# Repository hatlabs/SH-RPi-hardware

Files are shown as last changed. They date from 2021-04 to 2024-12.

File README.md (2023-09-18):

# Sailor Hat for Raspberry Pi (SH-RPi)

## Introduction

The Sailor Hat for Raspberry Pi (SH-RPi) is a versatile power management board designed for the Raspberry Pi and similar single-board computers. With the SH-RPi connected, you can create deeply integrated servers that shut down safely when power is turned off and wake up automatically when power is restored.

SH-RPi supports all Raspberry Pi models with a 40-pin GPIO header (every model since the Pi 1 Model B+). Additionally, it is compatible with Raspberry Pi Compute Module 4 boards and other single-board computers that have a 40-pin Raspberry Pi-compatible GPIO header or an external I2C interface with a 5V power input.

The [documentation site](https://docs.hatlabs.fi/sh-rpi/) has details on the hardware and software features of the board.

This repository contains the KiCad hardware design files for Sailor Hat.
There are two other related repositories: 
[firmware](https://github.com/hatlabs/SH-RPi-firmware) and 
[daemon](https://github.com/hatlabs/SH-RPi-daemon).

The documentation site is at [docs.hatlabs.fi/sh-rpi](https://docs.hatlabs.fi/). The devices are available for purchase at [shop.hatlabs.fi](https://shop.hatlabs.fi).

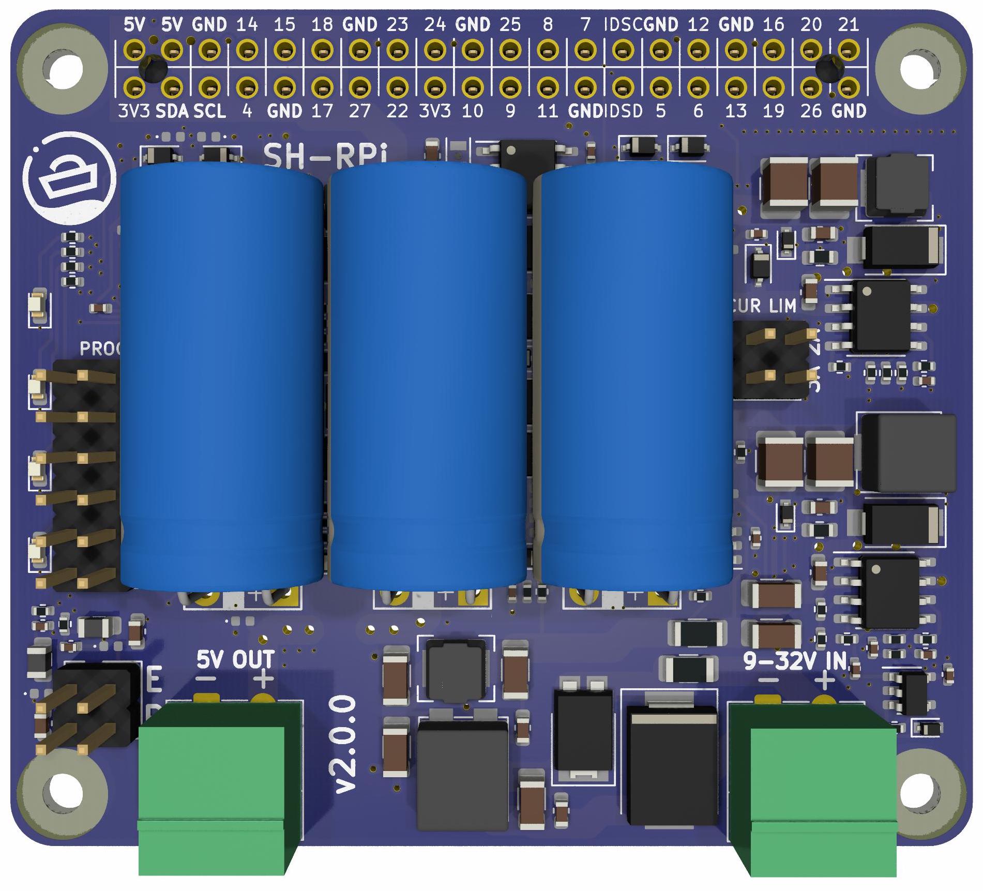
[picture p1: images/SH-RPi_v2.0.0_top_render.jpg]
SH-RPi v2.0.0


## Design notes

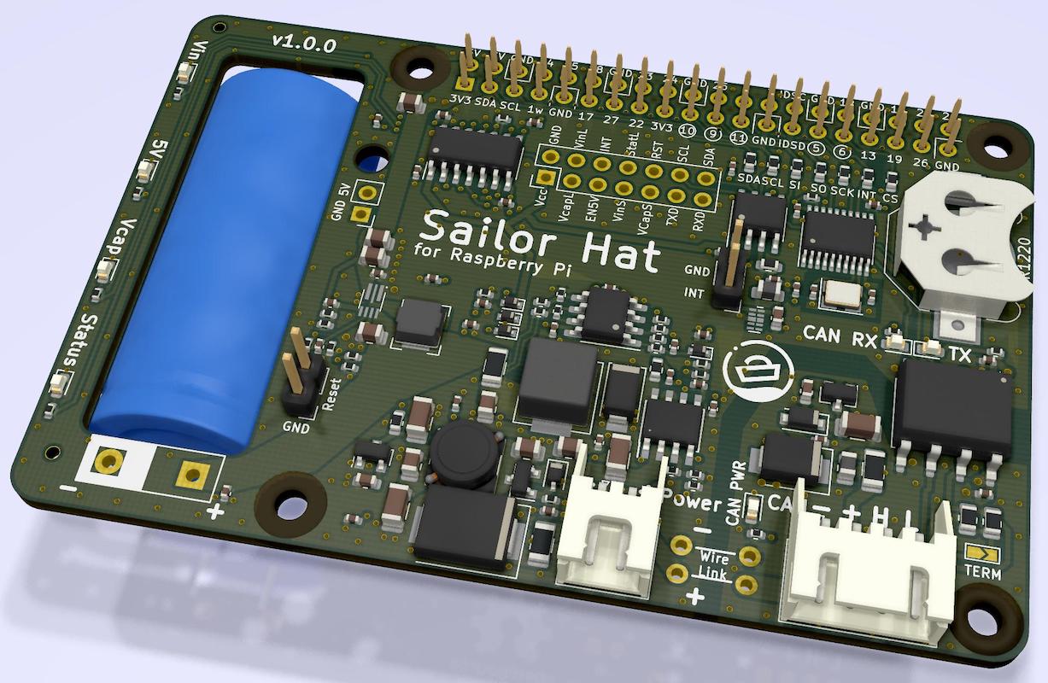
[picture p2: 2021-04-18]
images/SH-RPi-v1.0.0-render.jpg

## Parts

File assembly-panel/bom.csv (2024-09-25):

Comment | Designator | Footprint | LCSC
Conn_01x02 | J101,J502 | Connector_Phoenix_MC:PhoenixContact_MC_1,5_2-G-3.81_1x02_P3.81mm_Horizontal | C8387
100nF | C305,C306,C311,C312,C403,C406,C803,C1001,C1002,C1003 | Capacitor_SMD:C_0402_1005Metric | C1525
10k | R303,R311,R407,R409 | Resistor_SMD:R_0402_1005Metric | C25744
56k | R401 | Resistor_SMD:R_0402_1005Metric | C25796
2k | R404 | Resistor_SMD:R_0402_1005Metric | C4109
20k | R403 | Resistor_SMD:R_0402_1005Metric | C25765
150k | R402,R1005,R1008,R1011 | Resistor_SMD:R_0402_1005Metric | C25755
33pF 50V | C401,C402 | Capacitor_SMD:C_0603_1608Metric | C1663
33pF | C404,C405 | Capacitor_SMD:C_0402_1005Metric | C1562
GZ2012D601TF | FB401,FB402 | Inductor_SMD:L_0805_2012Metric | C1017
100R | R308,R405,R406 | Resistor_SMD:R_0402_1005Metric | C25076
ESD5451N | D401,D402,D501,D503,D505 | Diode_SMD:D_0402_1005Metric | C2936977
Conn_02x06_Odd_Even | J402 | Connector_PinHeader_2.54mm:PinHeader_2x06_P2.54mm_Vertical | C5383107
1k | R206,R408,R501,R502,R503,R504 | Resistor_SMD:R_0402_1005Metric | C11702
100k | R302,R410 | Resistor_SMD:R_0402_1005Metric | C25741
ATtiny1616-MNR | U401 | Package_DFN_QFN:VQFN-20-1EP_3x3mm_P0.4mm_EP1.7x1.7mm | C507118
Conn_02x02_Top_Bottom | J401 | Connector_PinHeader_2.54mm:PinHeader_2x02_P2.54mm_Vertical | C492419
100nF | C203,C308 | Capacitor_SMD:C_0603_1608Metric | C14663
SLO0530H3R3MTT | L301 | SH-RPi:L_MWSA0503S | C325963
47uF 16V | C309,C310 | Capacitor_SMD:C_1210_3225Metric | C77101
47k | R313 | Resistor_SMD:R_0402_1005Metric | C25792
470k | R312 | Resistor_SMD:R_0402_1005Metric | C25790
10m | R301 | Resistor_SMD:R_1206_3216Metric | C105362
1N4148WT | D201,D302,D305 | Diode_SMD:D_SOD-523 | C414017
5.1R | R202,R309 | Resistor_SMD:R_0603_1608Metric | C25197
68k | R204,R307 | Resistor_SMD:R_0402_1005Metric | C36871
SS56FL | D303 | Diode_SMD:D_SMA | C122865
1uF 50V | C303 | Capacitor_SMD:C_0603_1608Metric | C15849
10uF 50V | C301,C302,C702,C703,C704,C705 | Capacitor_SMD:C_1206_3216Metric | C13585
510R | R305 | Resistor_SMD:R_0402_1005Metric | C25123
RT6365 | U201,U301 | Package_SO:SOIC-8-1EP_3.9x4.9mm_P1.27mm_EP2.41x3.3mm_ThermalVias | C3024482
COS1333TR | U302 | Package_TO_SOT_SMD:SOT-23-5 | C693072
LMV321-TR | U303,U1001,U1002,U1003 | Package_TO_SOT_SMD:SOT-23-5 | C362273
1.5k | R310 | Resistor_SMD:R_0402_1005Metric | C25867
BZT52C3V3S | D301,D304 | Diode_SMD:D_SOD-323 | C173439
Conn_02x02 | J301 | Connector_PinHeader_2.54mm:PinHeader_2x02_P2.54mm_Vertical | C492419
3.9k | R316 | Resistor_SMD:R_0402_1005Metric | C51721
300k | R304,R1004,R1007,R1010,R1014,R1016,R1018 | Resistor_SMD:R_0402_1005Metric | C306602
3.3k | R314 | Resistor_SMD:R_0402_1005Metric | C25890
470pF | C304 | Capacitor_SMD:C_0402_1005Metric | C1537
7.5k | R315 | Resistor_SMD:R_0402_1005Metric | C25918
220nF | C307 | Capacitor_SMD:C_0402_1005Metric | C16772
MMBT5551 | Q301,Q302 | Package_TO_SOT_SMD:SOT-23 | C2145
LBSS84LT1G | Q303 | Package_TO_SOT_SMD:SOT-23 | C8492
MSK340A | D202 | Diode_SMD:D_SMA | C434027
47uF 6.3V | C204,C205 | Capacitor_SMD:C_1210_3225Metric | C77101
51k | R201 | Resistor_SMD:R_0402_1005Metric | C25794
27k | R203 | Resistor_SMD:R_0402_1005Metric | C25771
4.7uF | C201 | Capacitor_SMD:C_0603_1608Metric | C19666
3.3nF | C202 | Capacitor_SMD:C_0402_1005Metric | C26404
FXL0420-1R0-M | L201,L702 | SH-RPi:L_MWSA0402 | C167203
12k | R205 | Resistor_SMD:R_0402_1005Metric | C25752
22pF C0G | C802 | Capacitor_SMD:C_0603_1608Metric | C1653
1uF | C801 | Capacitor_SMD:C_0402_1005Metric | C52923
1N4148WS | D801,D802 | Diode_SMD:D_SOD-323 | C2128
PCF8563T | U801 | Package_SO:SOIC-8_3.9x4.9mm_P1.27mm | C7440
Conn_01x03 | J801 | SH-RPi:BatteryHolder_Myoung_MY-1220-03 | C964818
X1A000061000200 | Y801 | Crystal:Crystal_SMD_2012-2Pin_2.0x1.2mm | C55208
5.0SMDJ33CA | D701 | Diode_SMD:D_SMC | C2913642
12T.40000063AG12S1B02 | F701 | Fuse:Fuse_1206_3216Metric | C140479
1R | R701 | Capacitor_SMD:C_0603_1608Metric | C22936
100nF 50V | C701 | Capacitor_SMD:C_0603_1608Metric | C14663
PCAQ7060MW-102 | L701 | SH-RPi:L_CMF7060F | C2915648
10S45SP | D702 | SH-RPi:SS5U100_TO-277 | C2988031
Raspberry_Pi_2_3 | J501 | SH-RPi:PassthroughPinSocket_FH-00339_2x40_P2.54mm_Vertical_Bottom | C2685112
WHITE LED | D506,D507,D508,D509 | LED_SMD:LED_0603_1608Metric | C434422
1N5819WS | D502,D504,D901,D1001,D1002,D1003 | Diode_SMD:D_SOD-323_HandSoldering | C191023
1uF 16V | C901 | Capacitor_SMD:C_0402_1005Metric | C52923
10uF 6.3V | C902 | Capacitor_SMD:C_0402_1005Metric | C15525
HT7533-1 | U901 | Package_TO_SOT_SMD:SOT-23 | C5279052
33k | R1001,R1002,R1003 | Resistor_SMD:R_0402_1005Metric | C25779
120k | R1006,R1009,R1012 | Resistor_SMD:R_0402_1005Metric | C25750
SS8050 | Q1001,Q1002,Q1003 | Package_TO_SOT_SMD:SOT-23 | C2150
330k | R1013,R1015,R1017 | Resistor_SMD:R_0402_1005Metric | C25778

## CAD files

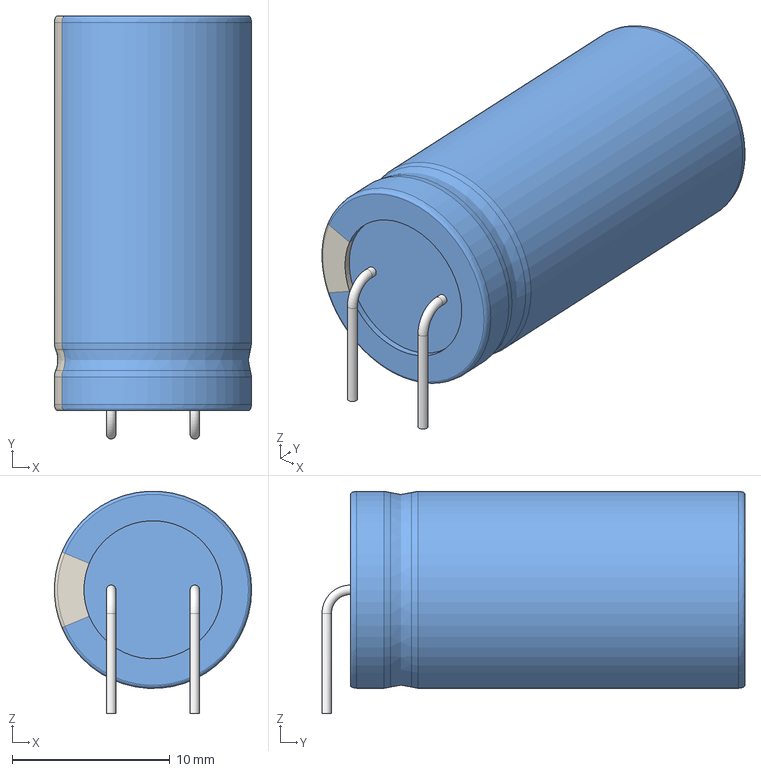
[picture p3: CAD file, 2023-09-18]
3D-models/CP_Radial_L25_D12.5_P5.3_Horizontal.step
12.5 x 26.8 x 14.1 mm

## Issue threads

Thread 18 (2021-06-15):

Schematics in jpg format

binu8051, 2021-06-15:
Hi
Can you post the schematic in jpg/png format.
i need to view the power supply section.
Thanks
Binu

mairas, 2021-06-15:
You can install KiCAD and do that yourself.

Closed 2021-06-15.

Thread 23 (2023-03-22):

Ideas for hardware

mgrouch, 2023-03-22:
In case if you are planning to build some other hardware for pi.
I’ve created a list of issues I’d have with design of another hat for pi. I hope it can help you with new designs (in case there are plans for it)

here is the link
https://github.com/OpenMarine/MacArthur-HAT/issues?q=author%3Amgrouch+

Thanks

Closed 2023-05-21.

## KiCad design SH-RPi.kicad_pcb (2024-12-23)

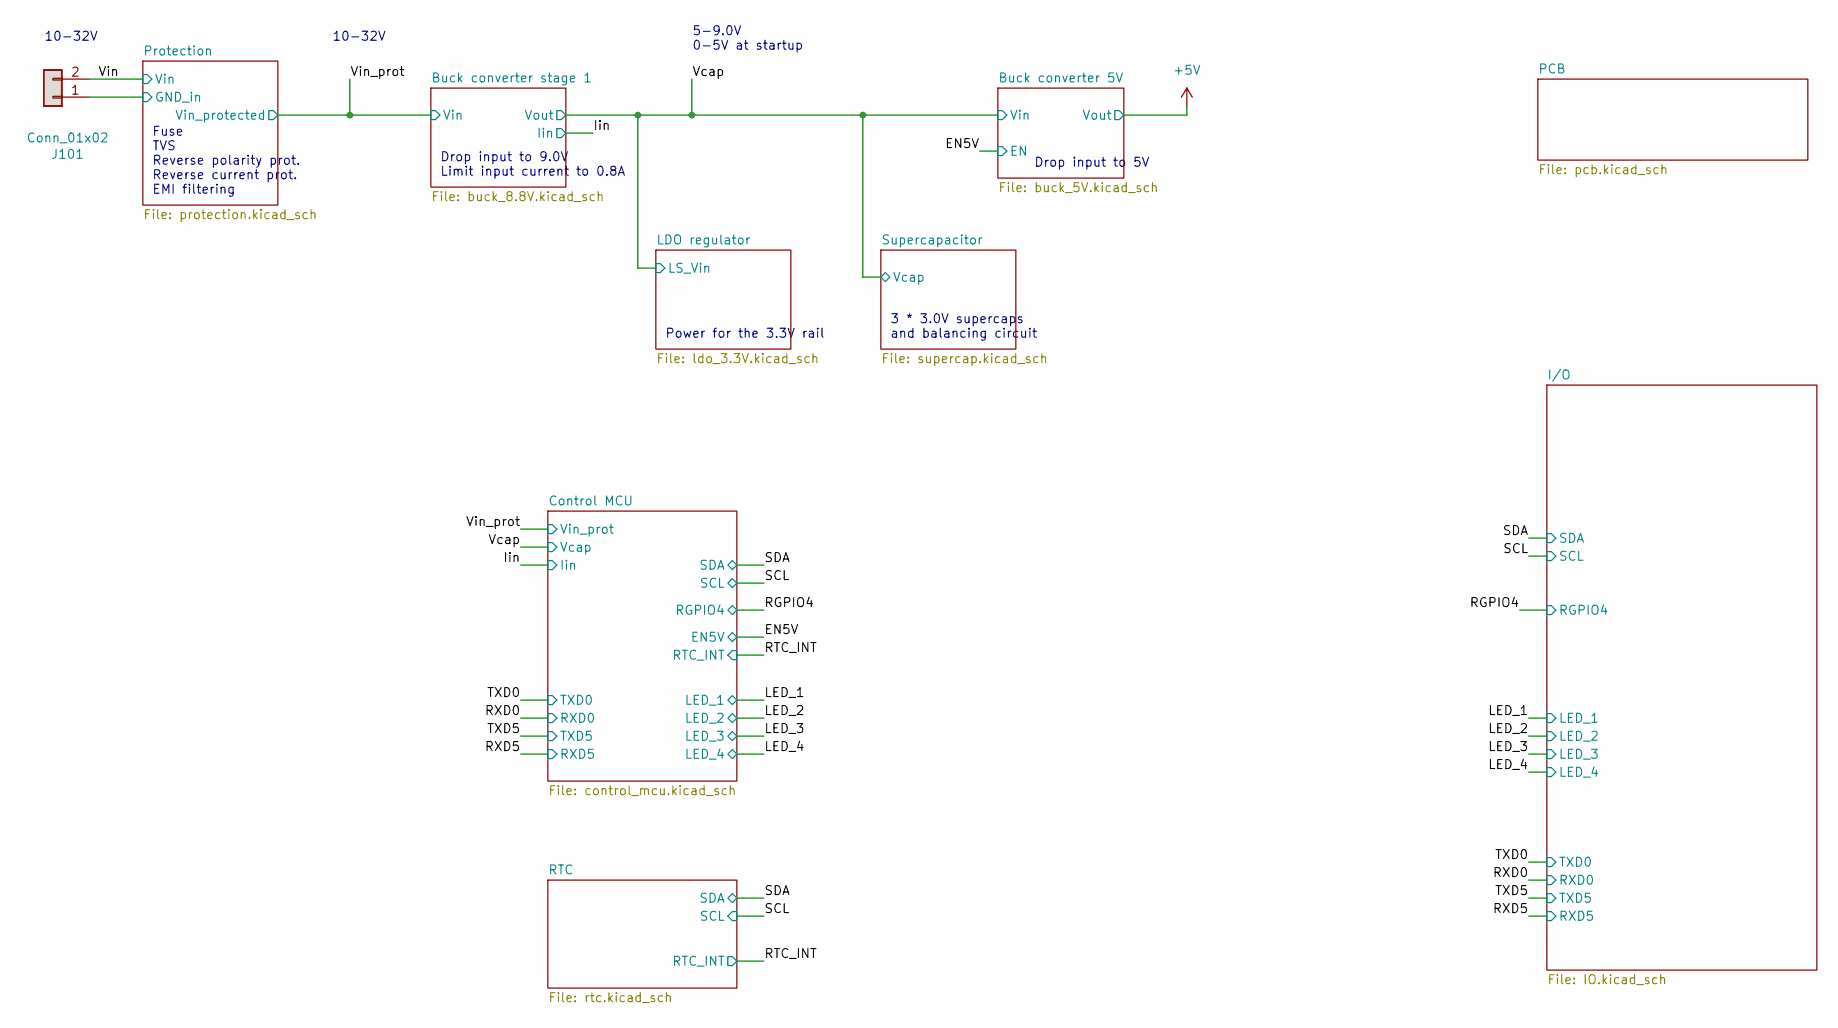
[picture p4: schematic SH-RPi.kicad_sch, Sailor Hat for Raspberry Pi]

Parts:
J101: Conn_01x02; PhoenixContact_MC_1,5_2-G-3.81_1x02_P3.81mm_Horizontal; LCSC C8387

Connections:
/Protection/GND_in: J101.1; also elsewhere on the board
/Vin: J101.2; also elsewhere on the board

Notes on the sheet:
Power for the 3.3V rail
Drop input to 5V
3 * 3.0V supercaps and balancing circuit
5-9.0V 0-5V at startup
10-32V
Fuse TVS Reverse polarity prot. Reverse current prot. EMI filtering
Drop input to 9.0V Limit input current to 0.8A

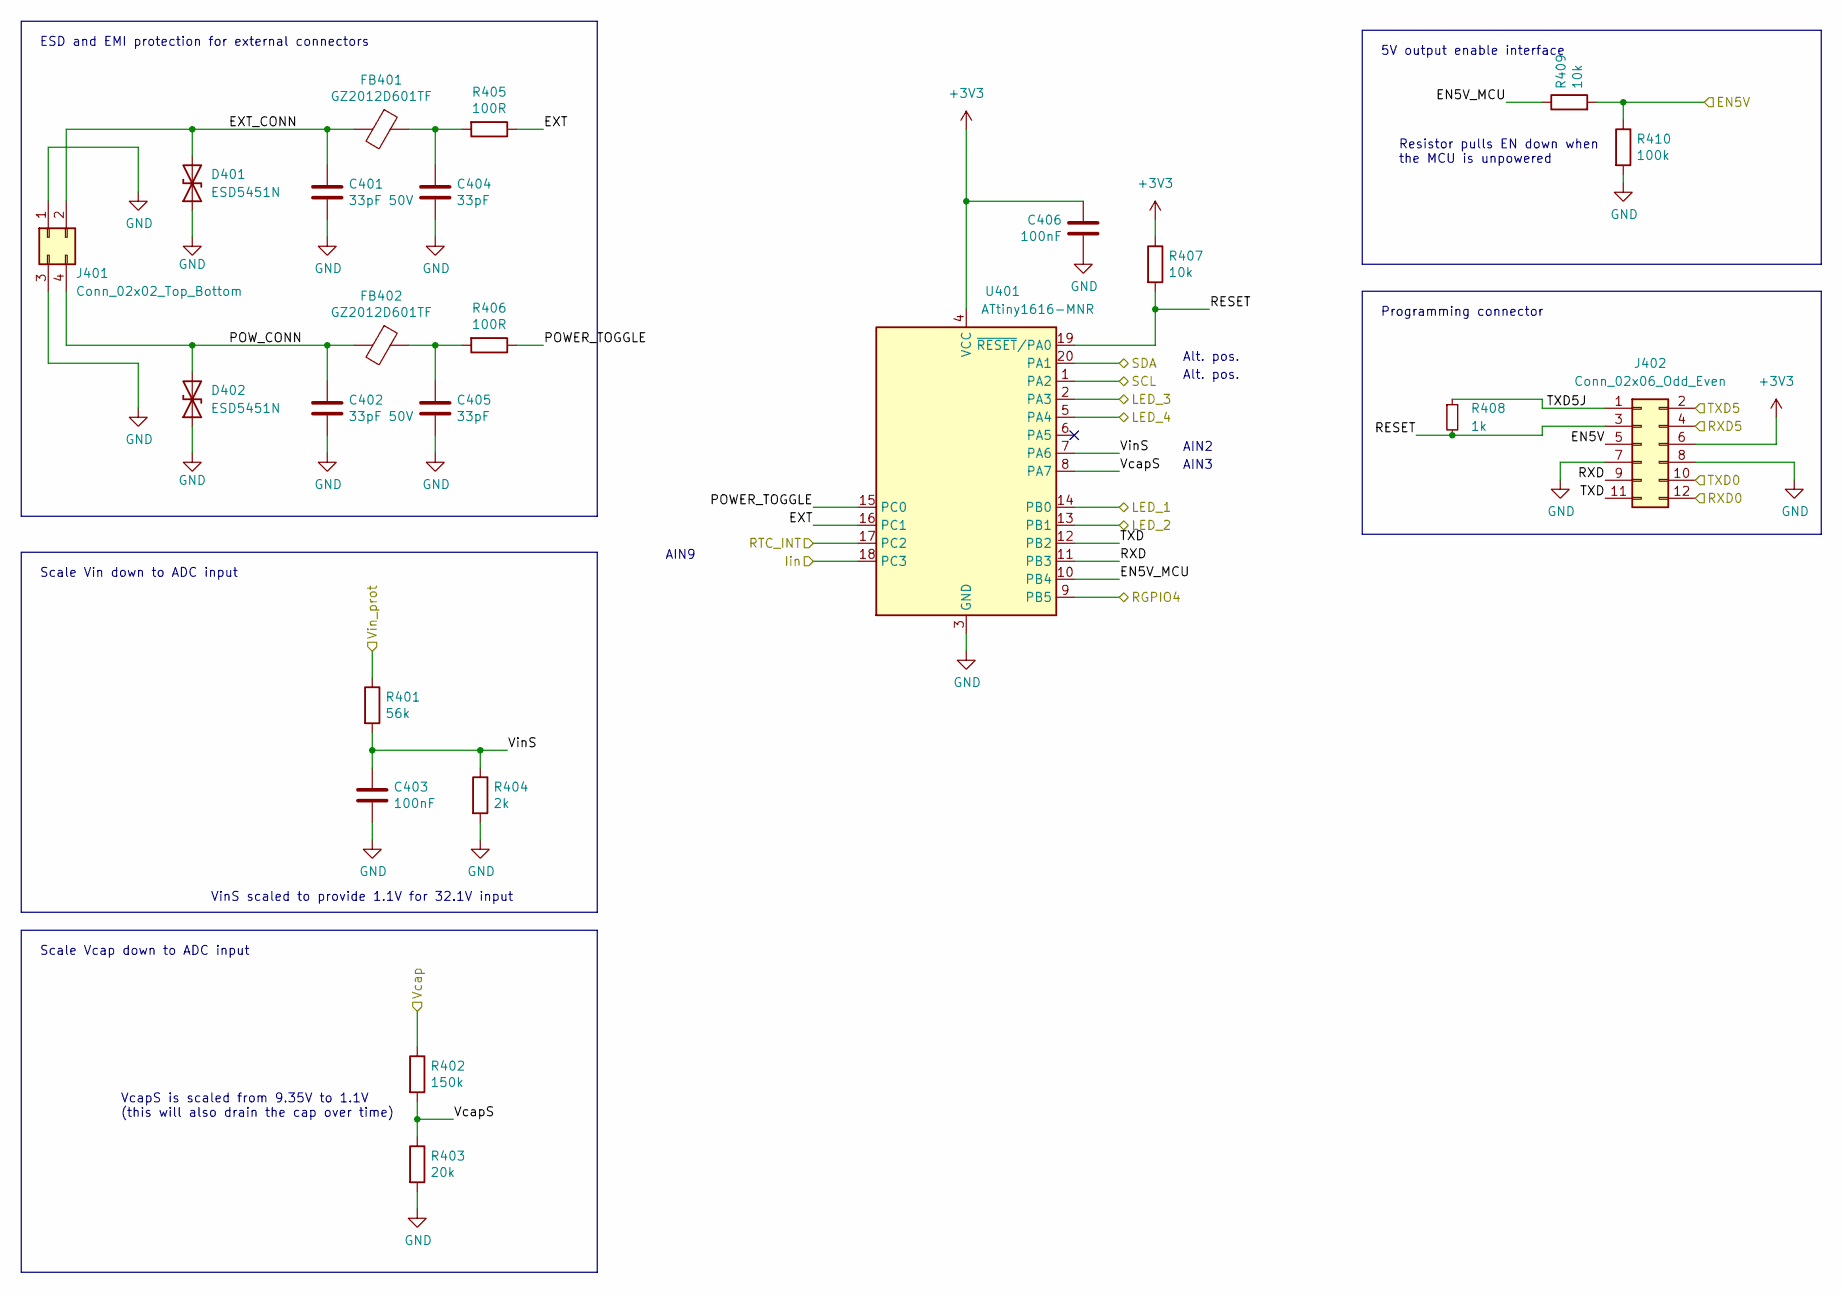
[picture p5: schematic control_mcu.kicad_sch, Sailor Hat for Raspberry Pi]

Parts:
C401, C402: 33pF 50V; C_0603_1608Metric; LCSC C1663
C403, C406: 100nF; C_0402_1005Metric; LCSC C1525
C404, C405: 33pF; C_0402_1005Metric; LCSC C1562
D401, D402: ESD5451N; D_0402_1005Metric; LCSC C2936977
FB401, FB402: GZ2012D601TF; L_0805_2012Metric; LCSC C1017
J401: Conn_02x02_Top_Bottom; PinHeader_2x02_P2.54mm_Vertical; LCSC C492419
J402: Conn_02x06_Odd_Even; PinHeader_2x06_P2.54mm_Vertical; LCSC C5383107
R401: 56k; R_0402_1005Metric; LCSC C25796
R402: 150k; R_0402_1005Metric; LCSC C25755
R403: 20k; R_0402_1005Metric; LCSC C25765
R404: 2k; R_0402_1005Metric; LCSC C4109
R405, R406: 100R; R_0402_1005Metric; LCSC C25076
R407, R409: 10k; R_0402_1005Metric; LCSC C25744
R408: 1k; R_0402_1005Metric; LCSC C11702
R410: 100k; R_0402_1005Metric; LCSC C25741
U401: ATtiny1616-MNR; VQFN-20-1EP_3x3mm_P0.4mm_EP1.7x1.7mm; LCSC C507118

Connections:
+3V3: C406.1, J402.6, R407.1, U401.4 (VCC); also elsewhere on the board
/Control MCU/EN5V_MCU: R409.1, U401.10 (PB4)
/Control MCU/EXT: R405.1, U401.16 (PC1)
/Control MCU/EXT_CONN: C401.1, D401.2 (A2), FB401.2, J401.2
/Control MCU/POWER_TOGGLE: R406.1, U401.15 (PC0)
/Control MCU/POW_CONN: C402.1, D402.2 (A2), FB402.2, J401.4
/Control MCU/RESET: J402.3, R407.2, R408.2, U401.19 (~RESET/PA0)
/Control MCU/RXD: J402.9, U401.11 (PB3)
/Control MCU/TXD: J402.11, U401.12 (PB2)
/Control MCU/TXD5J: J402.1, R408.1
/Control MCU/VcapS: R402.2, R403.1, U401.8 (PA7)
/Control MCU/VinS: C403.1, R401.2, R404.1, U401.7 (PA6)
/EN5V: J402.5, R409.2, R410.1; also elsewhere on the board
/Iin: U401.18 (PC3); also elsewhere on the board
/LED_1: U401.14 (PB0); also elsewhere on the board
/LED_2: U401.13 (PB1); also elsewhere on the board
/LED_3: U401.2 (PA3); also elsewhere on the board
/LED_4: U401.5 (PA4); also elsewhere on the board
/RGPIO4: U401.9 (PB5); also elsewhere on the board
/RTC_INT: U401.17 (PC2); also elsewhere on the board
/RXD0: J402.12; also elsewhere on the board
/RXD5: J402.4; also elsewhere on the board
/SCL: U401.1 (PA2); also elsewhere on the board
/SDA: U401.20 (PA1); also elsewhere on the board
/TXD0: J402.10; also elsewhere on the board
/TXD5: J402.2; also elsewhere on the board
/Vcap: R402.1; also elsewhere on the board
/Vin_prot: R401.1; also elsewhere on the board
GND: C401.2, C402.2, C403.2, C404.2, C405.2, C406.2, D401.1 (A1), D402.1 (A1), J401.1, J401.3, J402.7, J402.8, R403.2, R404.2, R410.2, U401.3 (GND), U401.21 (GND); also elsewhere on the board
unnamed: C404.1, FB401.1, R405.2
unnamed: C405.1, FB402.1, R406.2

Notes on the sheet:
Resistor pulls EN down when the MCU is unpowered
AIN2
Scale Vin down to ADC input
Programming connector
Scale Vcap down to ADC input
Alt. pos.
VinS scaled to provide 1.1V for 32.1V input
ESD and EMI protection for external connectors
AIN9
5V output enable interface
AIN3
VcapS is scaled from 9.35V to 1.1V (this will also drain the cap over time)

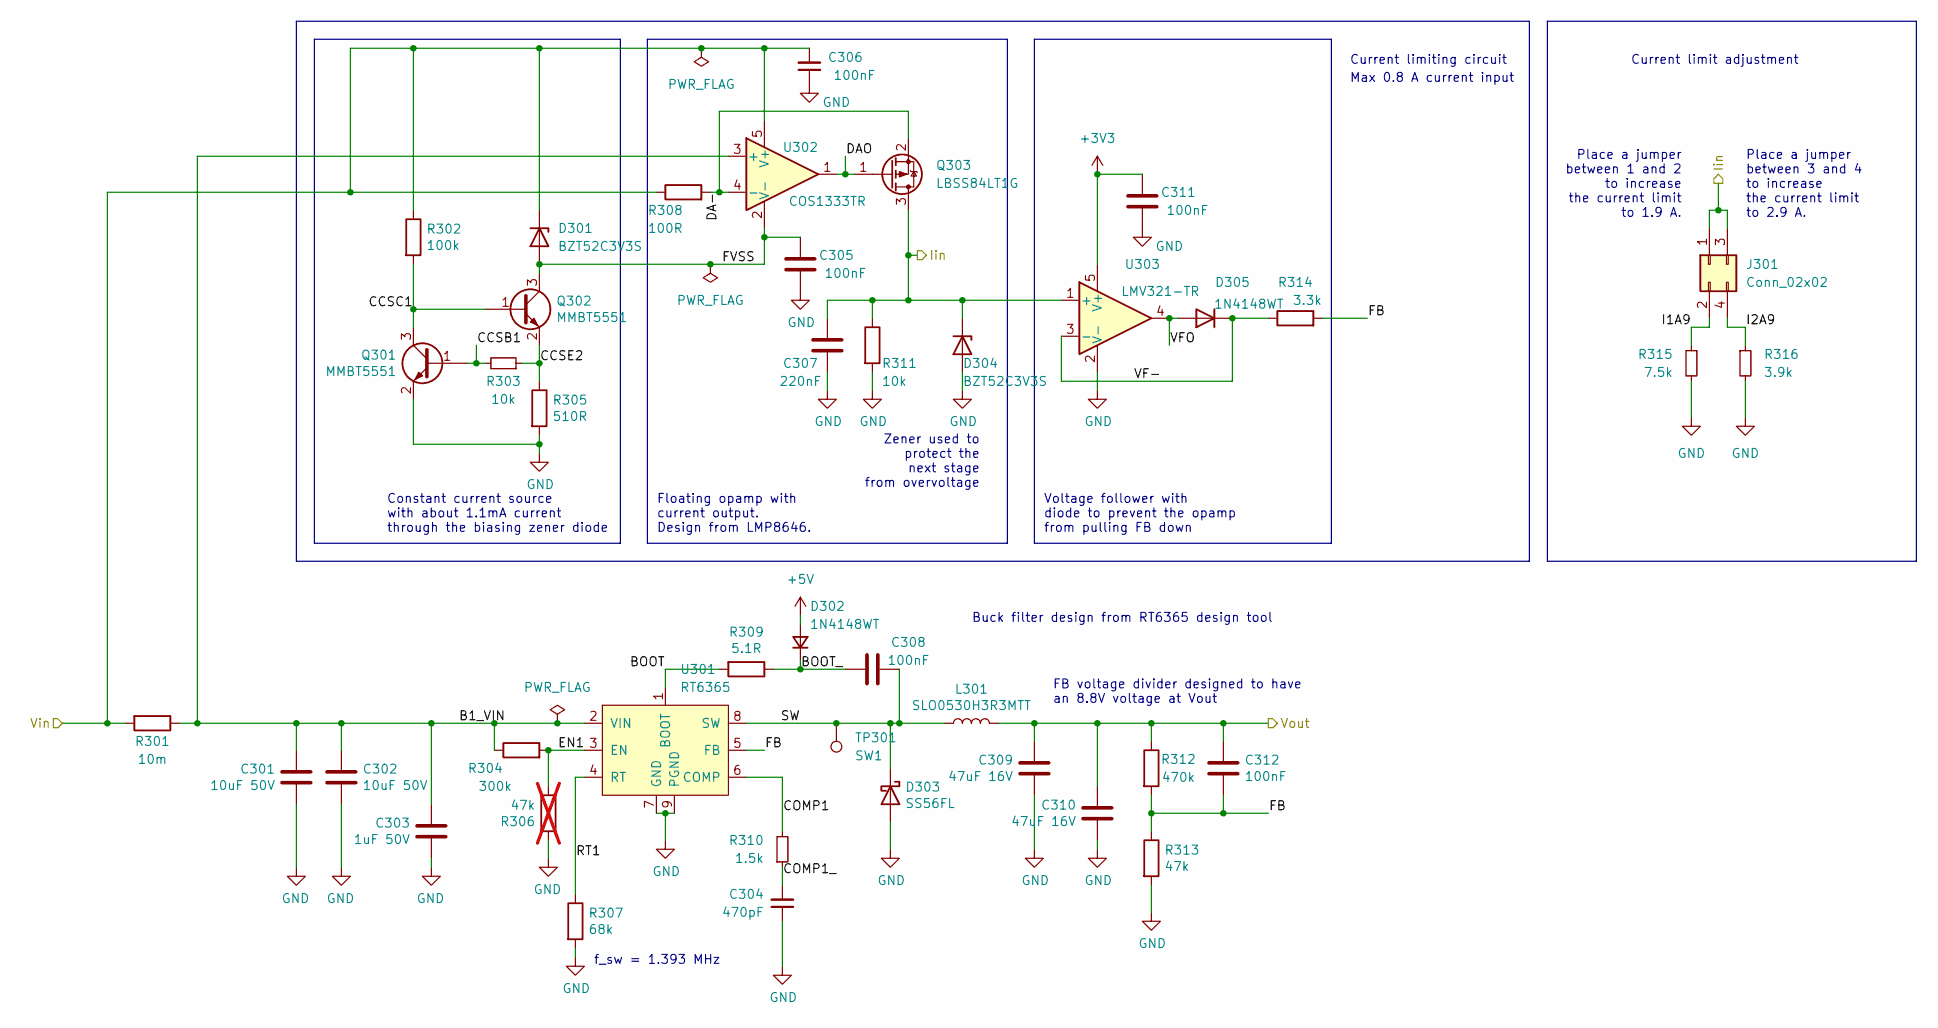
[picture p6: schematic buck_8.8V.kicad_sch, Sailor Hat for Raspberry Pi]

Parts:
C301, C302: 10uF 50V; C_1206_3216Metric; LCSC C13585
C303: 1uF 50V; C_0603_1608Metric; LCSC C15849
C304: 470pF; C_0402_1005Metric; LCSC C1537
C305, C306, C311, C312: 100nF; C_0402_1005Metric; LCSC C1525
C307: 220nF; C_0402_1005Metric; LCSC C16772
C308: 100nF; C_0603_1608Metric; LCSC C14663
C309, C310: 47uF 16V; C_1210_3225Metric; LCSC C77101
D301, D304: BZT52C3V3S; D_SOD-323; LCSC C173439
D302, D305: 1N4148WT; D_SOD-523; LCSC C414017
D303: SS56FL; D_SMA; LCSC C122865
J301: Conn_02x02; PinHeader_2x02_P2.54mm_Vertical; LCSC C492419
L301: SLO0530H3R3MTT; L_MWSA0503S; LCSC C325963
Q301, Q302: MMBT5551; SOT-23; LCSC C2145
Q303: LBSS84LT1G; SOT-23; LCSC C8492
R301: 10m; R_1206_3216Metric; LCSC C105362
R302: 100k; R_0402_1005Metric; LCSC C25741
R303, R311: 10k; R_0402_1005Metric; LCSC C25744
R304: 300k; R_0402_1005Metric; LCSC C306602
R305: 510R; R_0402_1005Metric; LCSC C25123
R306: 47k; R_0402_1005Metric; LCSC C25792; not fitted
R307: 68k; R_0402_1005Metric; LCSC C36871
R308: 100R; R_0402_1005Metric; LCSC C25076
R309: 5.1R; R_0603_1608Metric; LCSC C25197
R310: 1.5k; R_0402_1005Metric; LCSC C25867
R312: 470k; R_0402_1005Metric; LCSC C25790
R313: 47k; R_0402_1005Metric; LCSC C25792
R314: 3.3k; R_0402_1005Metric; LCSC C25890
R315: 7.5k; R_0402_1005Metric; LCSC C25918
R316: 3.9k; R_0402_1005Metric; LCSC C51721
TP301: SW1; TestPoint_Pad_D2.0mm
U301: RT6365; SOIC-8-1EP_3.9x4.9mm_P1.27mm_EP2.41x3.3mm_ThermalVias; LCSC C3024482
U302: COS1333TR; SOT-23-5; LCSC C693072
U303: LMV321-TR; SOT-23-5; LCSC C362273

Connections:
+3V3: C311.2, U303.5 (V+); also elsewhere on the board
+5V: D302.2 (A); also elsewhere on the board
/Buck converter stage 1/B1_VIN: C301.1, C302.1, C303.1, R301.1, R304.1, U301.2 (VIN), U302.3 (+)
/Buck converter stage 1/BOOT: R309.2, U301.1 (BOOT)
/Buck converter stage 1/BOOT_: C308.2, D302.1 (K), R309.1
/Buck converter stage 1/CCSB1: Q301.1 (B), R303.2
/Buck converter stage 1/CCSC1: Q301.3 (C), Q302.1 (B), R302.2
/Buck converter stage 1/CCSE2: Q302.2 (E), R303.1, R305.1
/Buck converter stage 1/COMP1: R310.2, U301.6 (COMP)
/Buck converter stage 1/COMP1_: C304.2, R310.1
/Buck converter stage 1/DA-: Q303.2 (S), R308.2, U302.4 (-)
/Buck converter stage 1/DAO: Q303.1 (G), U302.1
/Buck converter stage 1/EN1: R304.2, R306.2, U301.3 (EN)
/Buck converter stage 1/FB: C312.2, R312.2, R313.1, R314.2, U301.5 (FB)
/Buck converter stage 1/FVSS: C305.2, D301.2 (A), Q302.3 (C), U302.2 (V-)
/Buck converter stage 1/I1A9: J301.2, R315.1
/Buck converter stage 1/I2A9: J301.4, R316.1
/Buck converter stage 1/RT1: R307.1, U301.4 (RT)
/Buck converter stage 1/SW: C308.1, D303.1 (K), L301.1, TP301.1, U301.8 (SW)
/Buck converter stage 1/VF-: D305.1 (K), R314.1, U303.3 (-)
/Buck converter stage 1/VFO: D305.2 (A), U303.4
/Iin: C307.2, D304.1 (K), J301.1, J301.3, Q303.3 (D), R311.1, U303.1 (+); also elsewhere on the board
/Vcap: C309.1, C310.1, C312.1, L301.2, R312.1; also elsewhere on the board
/Vin_prot: C306.2, D301.1 (K), R301.2, R302.1, R308.1, U302.5 (V+); also elsewhere on the board
GND: C301.2, C302.2, C303.2, C304.1, C305.1, C306.1, C307.1, C309.2, C310.2, C311.1, D303.2 (A), D304.2 (A), Q301.2 (E), R305.2, R306.1, R307.2, R311.2, R313.2, R315.2, R316.2, U301.7 (GND), U301.9 (PGND), U303.2 (V-); also elsewhere on the board

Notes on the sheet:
Voltage follower with diode to prevent the opamp from pulling FB down
Constant current source with about 1.1mA current through the biasing zener diode
f_sw = 1.393 MHz
Place a jumper between 1 and 2 to increase the current limit to 1.9 A.
Place a jumper between 3 and 4 to increase the current limit to 2.9 A.
Zener used to protect the next stage from overvoltage
FB voltage divider designed to have an 8.8V voltage at Vout
Buck filter design from RT6365 design tool
Max 0.8 A current input
Current limit adjustment
Floating opamp with current output. Design from LMP8646.
Current limiting circuit

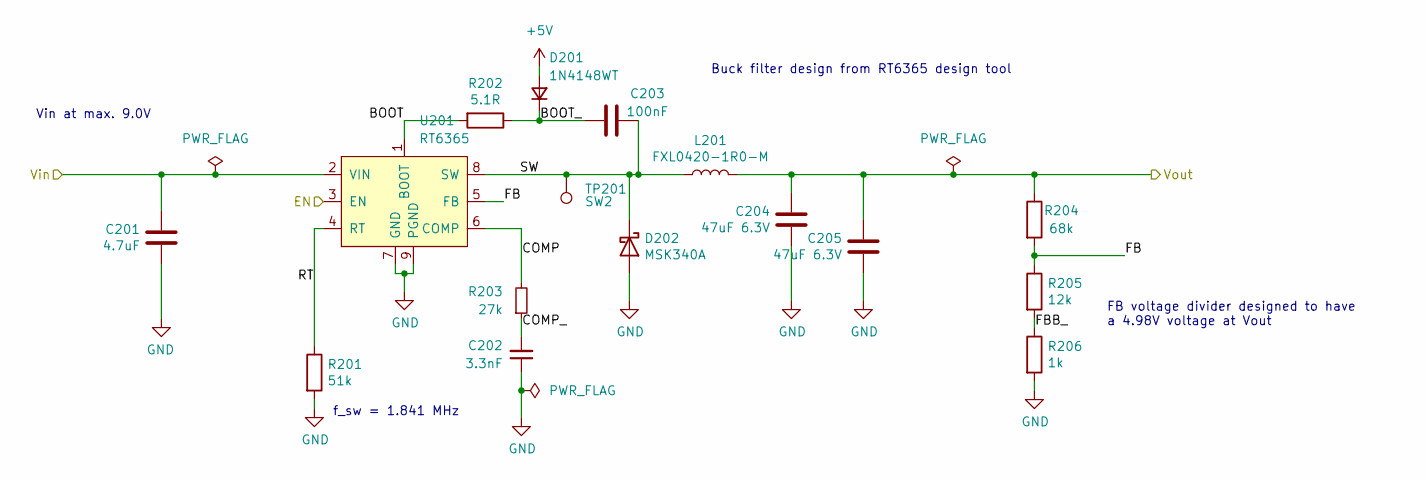
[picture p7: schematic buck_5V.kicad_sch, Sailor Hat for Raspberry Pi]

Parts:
C201: 4.7uF; C_0603_1608Metric; LCSC C19666
C202: 3.3nF; C_0402_1005Metric; LCSC C26404
C203: 100nF; C_0603_1608Metric; LCSC C14663
C204, C205: 47uF 6.3V; C_1210_3225Metric; LCSC C77101
D201: 1N4148WT; D_SOD-523; LCSC C414017
D202: MSK340A; D_SMA; LCSC C434027
L201: FXL0420-1R0-M; L_MWSA0402; LCSC C167203
R201: 51k; R_0402_1005Metric; LCSC C25794
R202: 5.1R; R_0603_1608Metric; LCSC C25197
R203: 27k; R_0402_1005Metric; LCSC C25771
R204: 68k; R_0402_1005Metric; LCSC C36871
R205: 12k; R_0402_1005Metric; LCSC C25752
R206: 1k; R_0402_1005Metric; LCSC C11702
TP201: SW2; TestPoint_Pad_D2.0mm
U201: RT6365; SOIC-8-1EP_3.9x4.9mm_P1.27mm_EP2.41x3.3mm_ThermalVias; LCSC C3024482

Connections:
+5V: C204.1, C205.1, D201.2 (A), L201.2, R204.1; also elsewhere on the board
/Buck converter stage 2/BOOT: R202.2, U201.1 (BOOT)
/Buck converter stage 2/BOOT_: C203.2, D201.1 (K), R202.1
/Buck converter stage 2/COMP: R203.2, U201.6 (COMP)
/Buck converter stage 2/COMP_: C202.2, R203.1
/Buck converter stage 2/FB: R204.2, R205.1, U201.5 (FB)
/Buck converter stage 2/FBB_: R205.2, R206.1
/Buck converter stage 2/RT: R201.1, U201.4 (RT)
/Buck converter stage 2/SW: C203.1, D202.1 (K), L201.1, TP201.1, U201.8 (SW)
/EN5V: U201.3 (EN); also elsewhere on the board
/Vcap: C201.1, U201.2 (VIN); also elsewhere on the board
GND: C201.2, C202.1, C204.2, C205.2, D202.2 (A), R201.2, R206.2, U201.7 (GND), U201.9 (PGND); also elsewhere on the board

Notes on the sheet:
FB voltage divider designed to have a 4.98V voltage at Vout
Vin at max. 9.0V
Buck filter design from RT6365 design tool
f_sw = 1.841 MHz

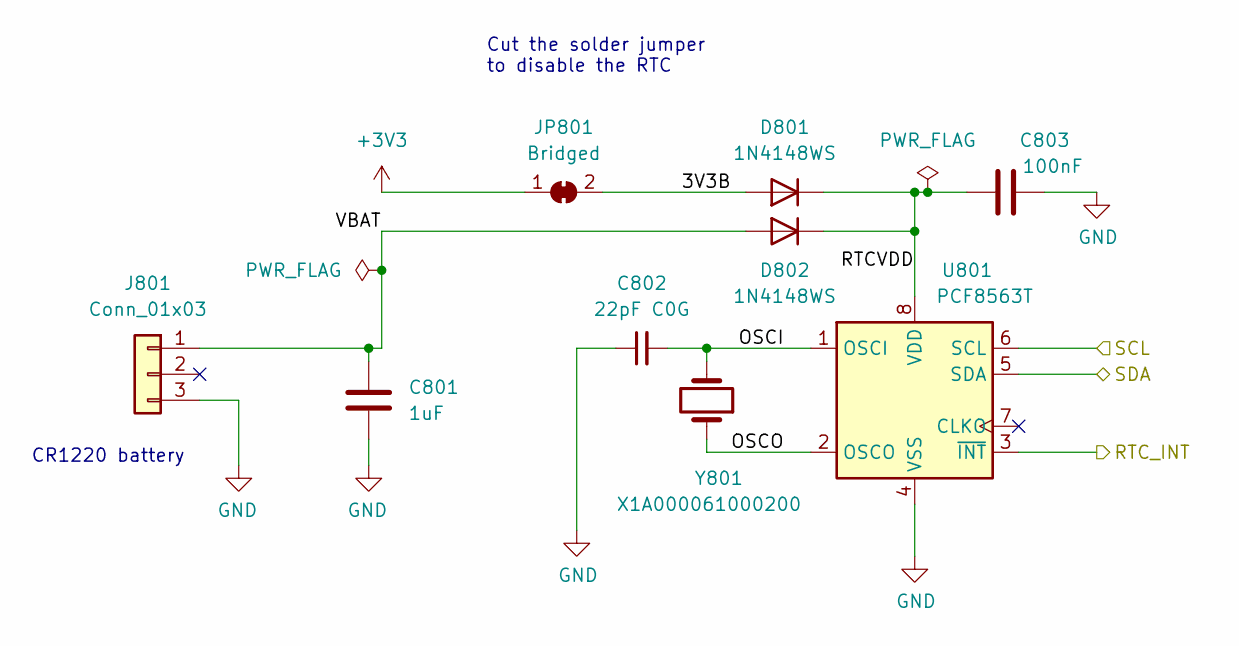
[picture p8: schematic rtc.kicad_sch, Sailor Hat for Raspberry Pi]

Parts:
C801: 1uF; C_0402_1005Metric; LCSC C52923
C802: 22pF C0G; C_0603_1608Metric; LCSC C1653
C803: 100nF; C_0402_1005Metric; LCSC C1525
D801, D802: 1N4148WS; D_SOD-323; LCSC C2128
J801: Conn_01x03; BatteryHolder_Myoung_MY-1220-03; LCSC C964818
JP801: Bridged; SolderJumper-2_P1.3mm_Bridged2Bar_Pad1.0x1.5mm
U801: PCF8563T; SOIC-8_3.9x4.9mm_P1.27mm; LCSC C7440
Y801: X1A000061000200; Crystal_SMD_2012-2Pin_2.0x1.2mm; LCSC C55208

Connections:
+3V3: JP801.1 (A); also elsewhere on the board
/RTC/3V3B: D801.2 (A), JP801.2 (B)
/RTC/OSCI: C802.2, U801.1 (OSCI), Y801.2
/RTC/OSCO: U801.2 (OSCO), Y801.1
/RTC/RTCVDD: C803.1, D801.1 (K), D802.1 (K), U801.8 (VDD)
/RTC/VBAT: C801.1, D802.2 (A), J801.1
/RTC_INT: U801.3 (~INT); also elsewhere on the board
/SCL: U801.6 (SCL); also elsewhere on the board
/SDA: U801.5 (SDA); also elsewhere on the board
GND: C801.2, C802.1, C803.2, J801.3, U801.4 (VSS); also elsewhere on the board

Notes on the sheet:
Cut the solder jumper to disable the RTC
CR1220 battery

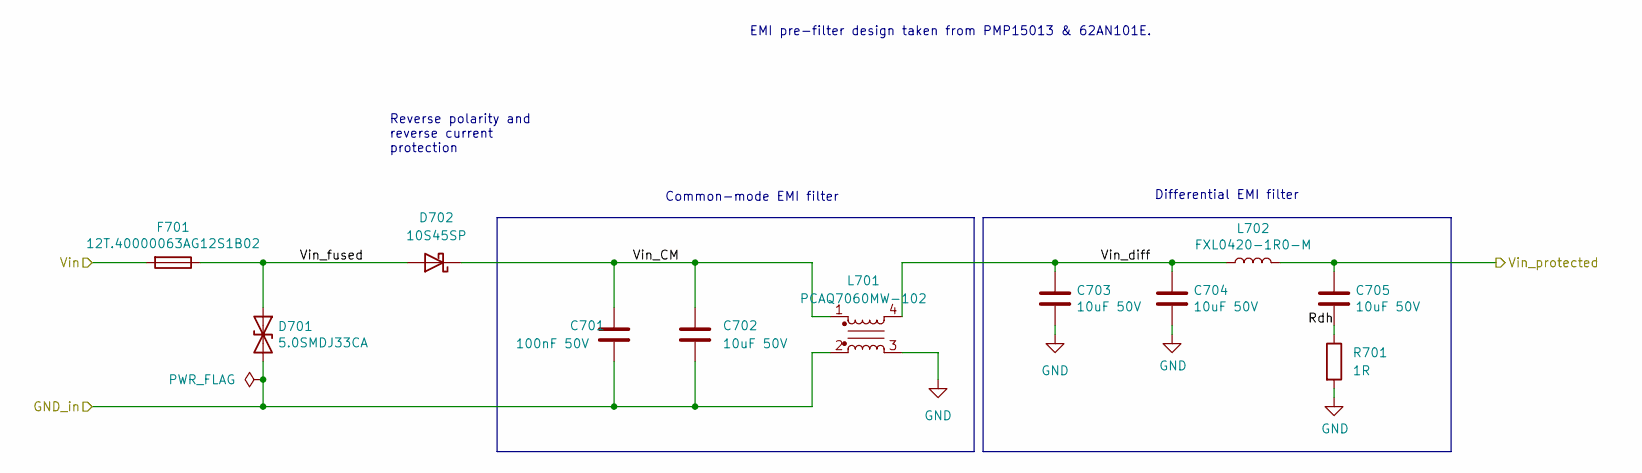
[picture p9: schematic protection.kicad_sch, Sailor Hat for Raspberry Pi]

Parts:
C701: 100nF 50V; C_0603_1608Metric; LCSC C14663
C702, C703, C704, C705: 10uF 50V; C_1206_3216Metric; LCSC C13585
D701: 5.0SMDJ33CA; D_SMC; LCSC C2913642
D702: 10S45SP; SS5U100_TO-277; LCSC C2988031
F701: 12T.40000063AG12S1B02; Fuse_1206_3216Metric; LCSC C140479
L701: PCAQ7060MW-102; L_CMF7060F; LCSC C2915648
L702: FXL0420-1R0-M; L_MWSA0402; LCSC C167203
R701: 1R; C_0603_1608Metric; LCSC C22936

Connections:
/Protection/GND_in: C701.2, C702.2, D701.2 (A2), L701.2; also elsewhere on the board
/Protection/Rdh: C705.2, R701.1
/Protection/Vin_CM: C701.1, C702.1, D702.1 (K), L701.1
/Protection/Vin_diff: C703.1, C704.1, L701.4, L702.1
/Protection/Vin_fused: D701.1 (A1), D702.2 (A), F701.1
/Vin: F701.2; also elsewhere on the board
/Vin_prot: C705.1, L702.2; also elsewhere on the board
GND: C703.2, C704.2, L701.3, R701.2; also elsewhere on the board

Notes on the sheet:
Reverse polarity and reverse current protection
EMI pre-filter design taken from PMP15013 & 62AN101E.
Differential EMI filter
Common-mode EMI filter

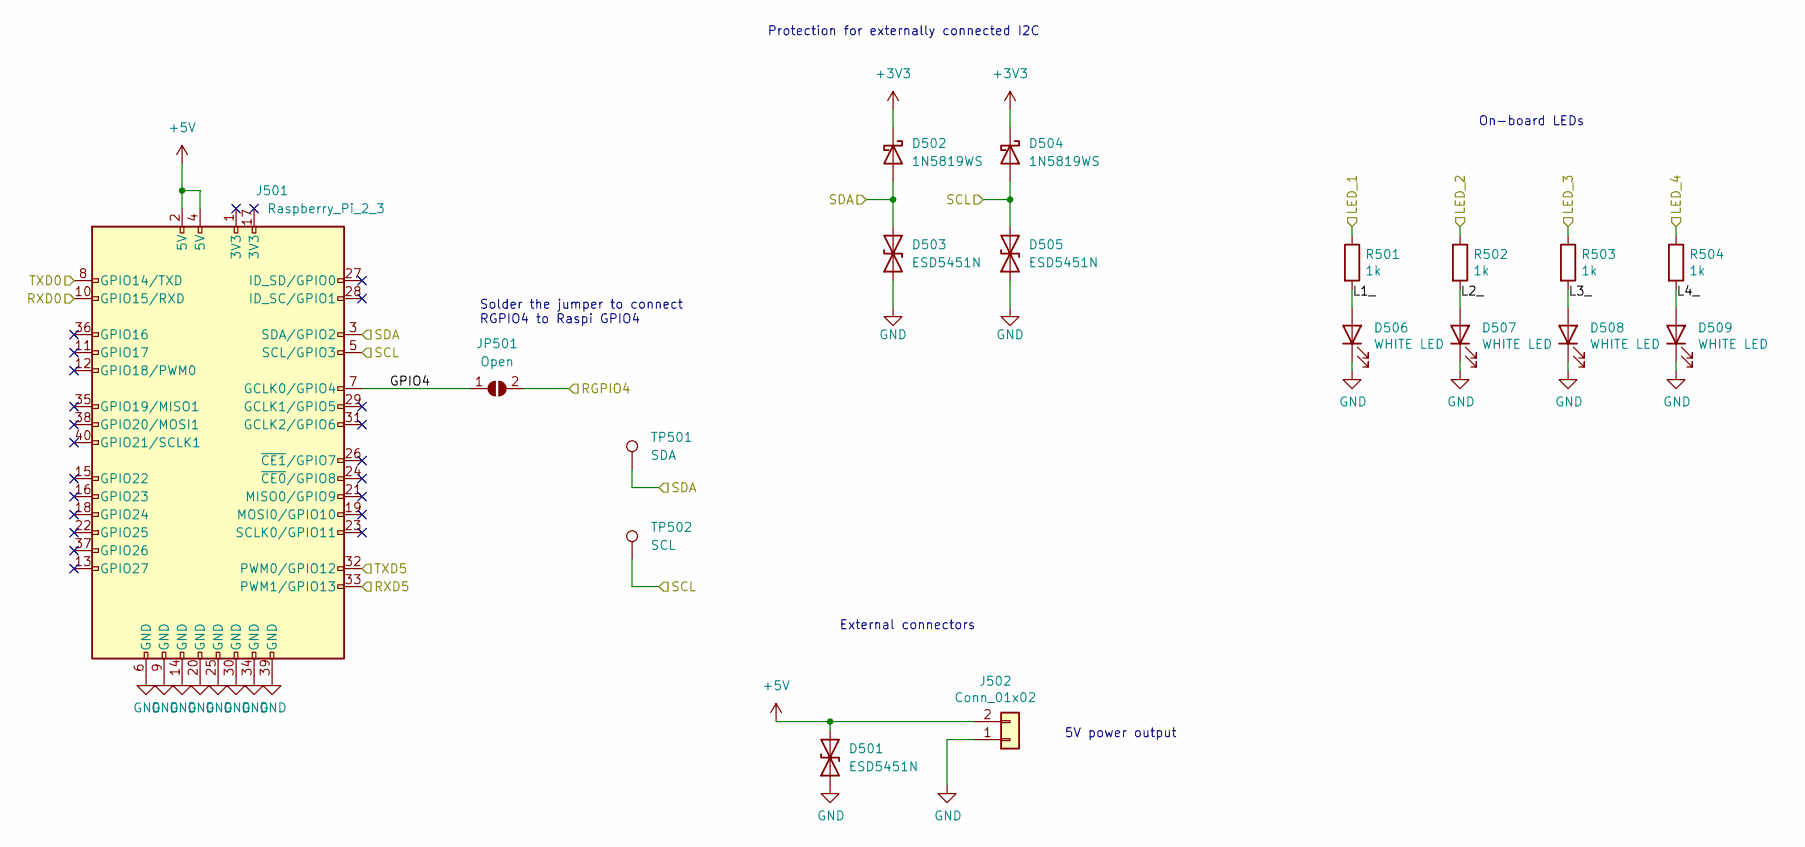
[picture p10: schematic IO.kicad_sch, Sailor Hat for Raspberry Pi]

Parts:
D501, D503, D505: ESD5451N; D_0402_1005Metric; LCSC C2936977
D502, D504: 1N5819WS; D_SOD-323_HandSoldering; LCSC C191023
D506, D507, D508, D509: WHITE LED; LED_0603_1608Metric; LCSC C434422
J501: Raspberry_Pi_2_3; PassthroughPinSocket_FH-00339_2x40_P2.54mm_Vertical_Bottom; LCSC C2685112
J502: Conn_01x02; PhoenixContact_MC_1,5_2-G-3.81_1x02_P3.81mm_Horizontal; LCSC C8387
JP501: Open; SolderJumper-2_P1.3mm_Open_TrianglePad1.0x1.5mm
R501, R502, R503, R504: 1k; R_0402_1005Metric; LCSC C11702
TP501: SDA; TestPoint_Pad_D2.0mm
TP502: SCL; TestPoint_Pad_D2.0mm

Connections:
+3V3: D502.1 (K), D504.1 (K); also elsewhere on the board
+5V: D501.2 (A2), J501.2 (5V), J501.4 (5V), J502.2; also elsewhere on the board
/I/O/GPIO4: J501.7 (GCLK0/GPIO4), JP501.1 (A)
/I/O/L1_: D506.2 (A), R501.2
/I/O/L2_: D507.2 (A), R502.2
/I/O/L3_: D508.2 (A), R503.2
/I/O/L4_: D509.2 (A), R504.2
/LED_1: R501.1; also elsewhere on the board
/LED_2: R502.1; also elsewhere on the board
/LED_3: R503.1; also elsewhere on the board
/LED_4: R504.1; also elsewhere on the board
/RGPIO4: JP501.2 (B); also elsewhere on the board
/RXD0: J501.10 (GPIO15/RXD); also elsewhere on the board
/RXD5: J501.33 (PWM1/GPIO13); also elsewhere on the board
/SCL: D504.2 (A), D505.2 (A2), J501.5 (SCL/GPIO3), TP502.1; also elsewhere on the board
/SDA: D502.2 (A), D503.2 (A2), J501.3 (SDA/GPIO2), TP501.1; also elsewhere on the board
/TXD0: J501.8 (GPIO14/TXD); also elsewhere on the board
/TXD5: J501.32 (PWM0/GPIO12); also elsewhere on the board
GND: D501.1 (A1), D503.1 (A1), D505.1 (A1), D506.1 (K), D507.1 (K), D508.1 (K), D509.1 (K), J501.6 (GND), J501.9 (GND), J501.14 (GND), J501.20 (GND), J501.25 (GND), J501.30 (GND), J501.34 (GND), J501.39 (GND), J502.1; also elsewhere on the board

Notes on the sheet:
On-board LEDs
Protection for externally connected I2C
External connectors
5V power output
Solder the jumper to connect RGPIO4 to Raspi GPIO4

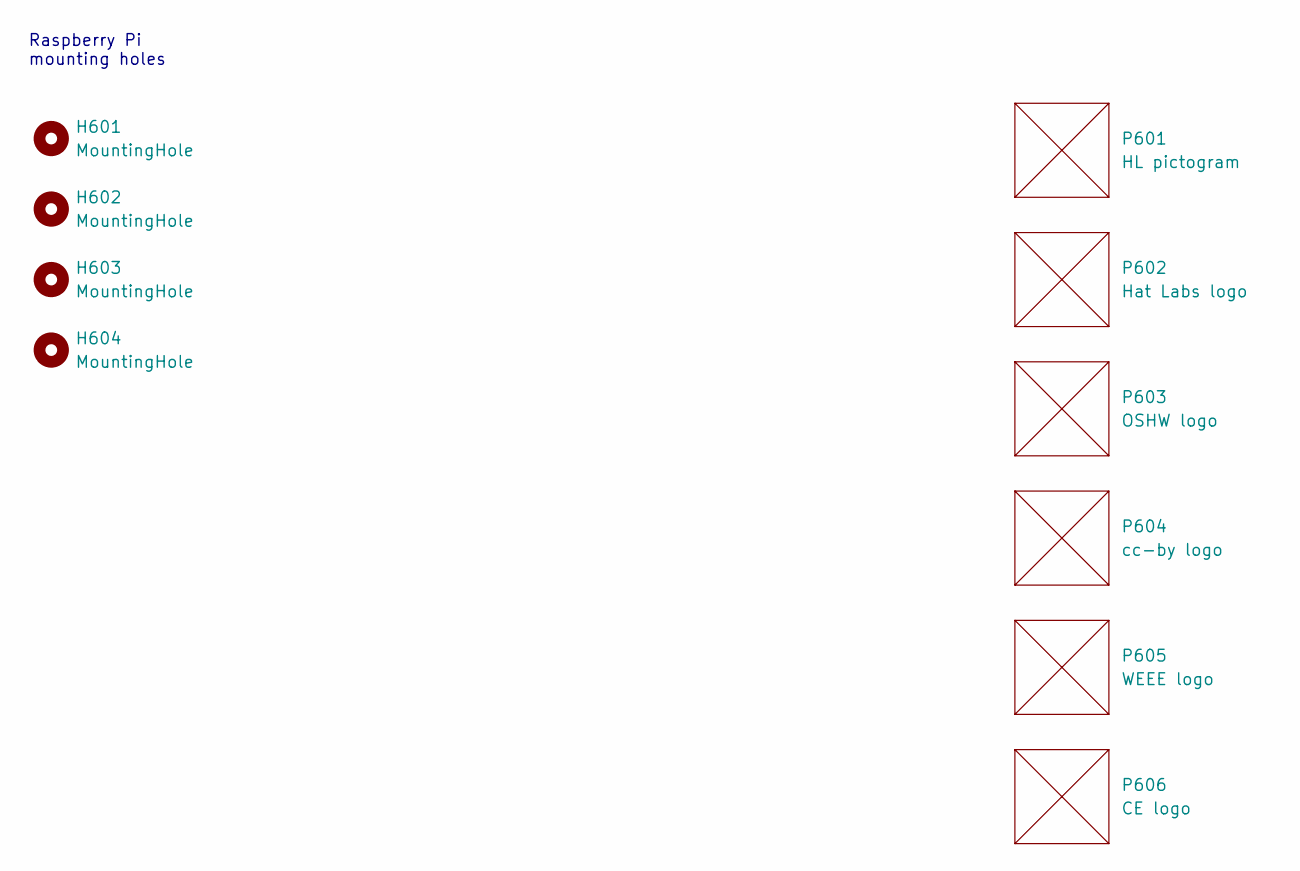
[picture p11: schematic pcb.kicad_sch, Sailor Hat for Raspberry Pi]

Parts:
H601, H602, H603, H604: MountingHole; MountingHole_Pi_2.75mm_M2.5
P601: HL pictogram; HL_pictogram_6.3mm
P602: Hat Labs logo; Hat_Labs_25.4mm
P603: OSHW logo; OSHW-Logo_11.4x12mm_SilkScreen
P604: cc-by logo; cc-by_5mm
P605: WEEE logo; WEEE-Logo_4.2x6mm_SilkScreen
P606: CE logo; CE-Logo_8.5x6mm_SilkScreen

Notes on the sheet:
Raspberry Pi mounting holes

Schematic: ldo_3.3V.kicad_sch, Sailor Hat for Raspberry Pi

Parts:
C901: 1uF 16V; C_0402_1005Metric; LCSC C52923
C902: 10uF 6.3V; C_0402_1005Metric; LCSC C15525
D901: 1N5819WS; D_SOD-323_HandSoldering; LCSC C191023
TP901: 3V3; TestPoint_Pad_D2.0mm
U901: HT7533-1; SOT-23; LCSC C5279052

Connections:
+3V3: C902.1, TP901.1, U901.2 (VOUT); also elsewhere on the board
/LDO regulator/LDO_in: C901.1, D901.1 (K), U901.3 (VIN)
/Vcap: D901.2 (A); also elsewhere on the board
GND: C901.2, C902.2, U901.1 (GND); also elsewhere on the board

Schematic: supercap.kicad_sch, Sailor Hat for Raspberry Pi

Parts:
C1001, C1002, C1003: 100nF; C_0402_1005Metric; LCSC C1525
C1004, C1005, C1006: CAS SCAP 3.0V20F; CP_Radial_D12.6mm_H26.0mm_P5.30mm_Horizontal; JLCPCB_IGNORE 1
D1001, D1002, D1003: 1N5819WS; D_SOD-323_HandSoldering; LCSC C191023
Q1001, Q1002, Q1003: SS8050; SOT-23; LCSC C2150
R1001, R1002, R1003: 33k; R_0402_1005Metric; LCSC C25779
R1004, R1007, R1010, R1014, R1016, R1018: 300k; R_0402_1005Metric; LCSC C306602
R1005, R1008, R1011: 150k; R_0402_1005Metric; LCSC C25755
R1006, R1009, R1012: 120k; R_0402_1005Metric; LCSC C25750
R1013, R1015, R1017: 330k; R_0402_1005Metric; LCSC C25778
U1001, U1002, U1003: LMV321-TR; SOT-23-5; LCSC C362273

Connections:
/Supercapacitor/BO1+: R1010.2, R1011.1, U1003.1 (+)
/Supercapacitor/BO1+_: R1011.2, R1012.1
/Supercapacitor/BO1-: R1017.2, R1018.1, U1003.3 (-)
/Supercapacitor/BO1o: Q1003.1 (B), U1003.4
/Supercapacitor/BO2+: R1007.2, R1008.1, U1002.1 (+)
/Supercapacitor/BO2+_: R1008.2, R1009.1
/Supercapacitor/BO2-: R1015.2, R1016.1, U1002.3 (-)
/Supercapacitor/BO2o: Q1002.1 (B), U1002.4
/Supercapacitor/BO3+: R1004.2, R1005.1, U1001.1 (+)
/Supercapacitor/BO3+_: R1005.2, R1006.1
/Supercapacitor/BO3-: R1013.2, R1014.1, U1001.3 (-)
/Supercapacitor/BO3o: Q1001.1 (B), U1001.4
/Supercapacitor/SC12: C1002.2, C1003.1, C1005.2, C1006.1, D1002.2 (A), D1003.1 (K), Q1002.2 (E), Q1003.3 (C), R1010.1, R1016.2, U1002.2 (V-), U1003.5 (V+)
/Supercapacitor/SC12R: R1002.2, R1003.1, R1009.2, R1017.1
/Supercapacitor/SC23: C1001.2, C1002.1, C1004.2, C1005.1, D1001.2 (A), D1002.1 (K), Q1001.2 (E), Q1002.3 (C), R1007.1, R1014.2, U1001.2 (V-), U1002.5 (V+)
/Supercapacitor/SC23R: R1001.2, R1002.1, R1006.2, R1015.1
/Vcap: C1001.1, C1004.1, D1001.1 (K), Q1001.3 (C), R1001.1, R1004.1, R1013.1, U1001.5 (V+); also elsewhere on the board
GND: C1003.2, C1006.2, D1003.2 (A), Q1003.2 (E), R1003.2, R1012.2, R1018.2, U1003.2 (V-); also elsewhere on the board

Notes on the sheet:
Balancing circuit modeled after https://www.eevblog.com/forum/renewable-energy/supercapacitor-balancer/

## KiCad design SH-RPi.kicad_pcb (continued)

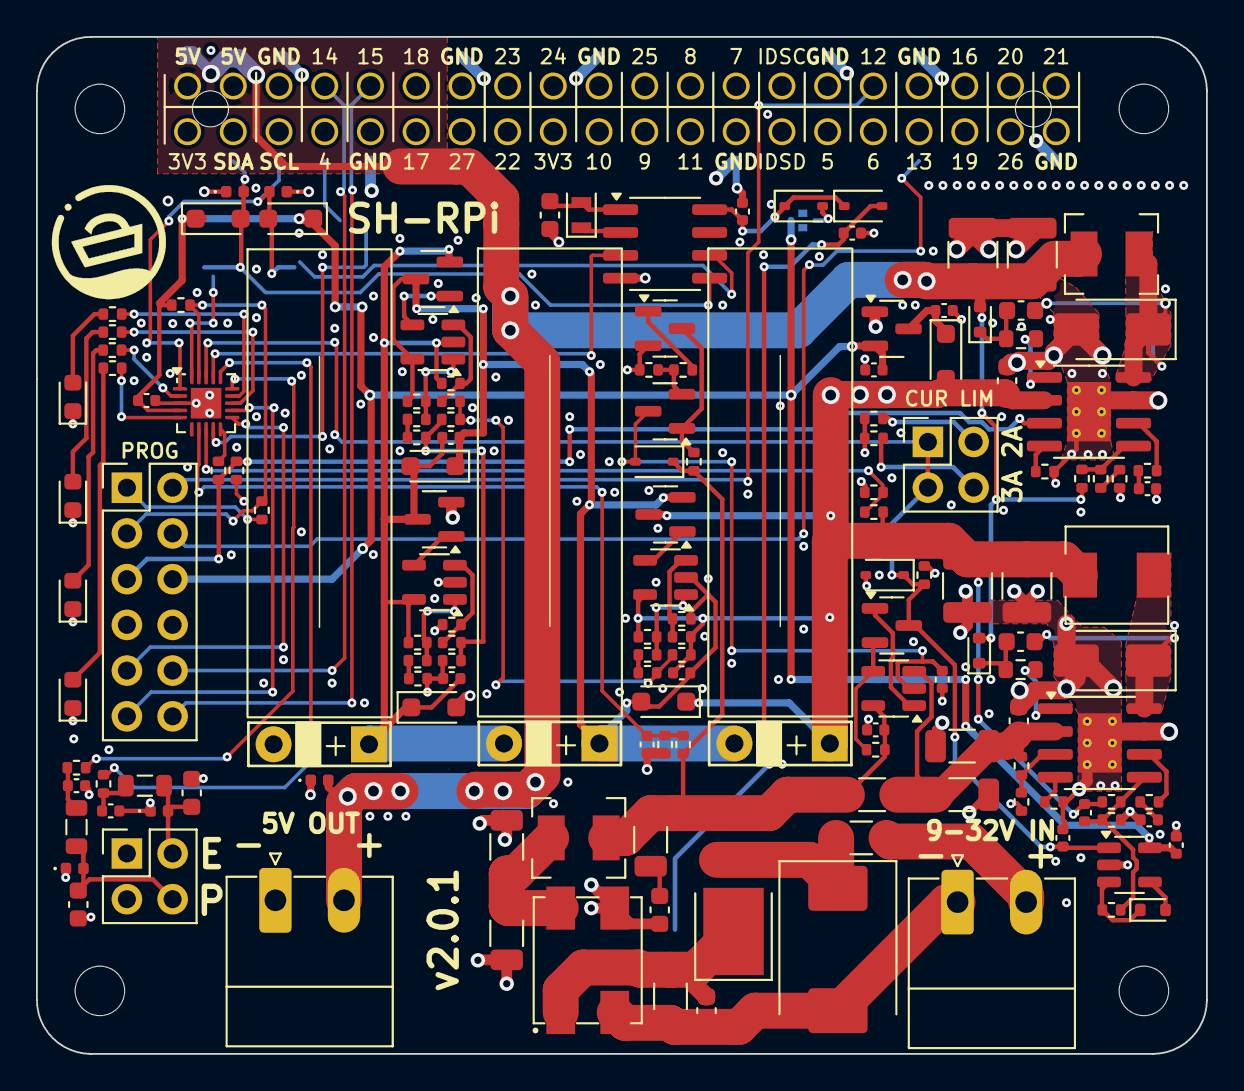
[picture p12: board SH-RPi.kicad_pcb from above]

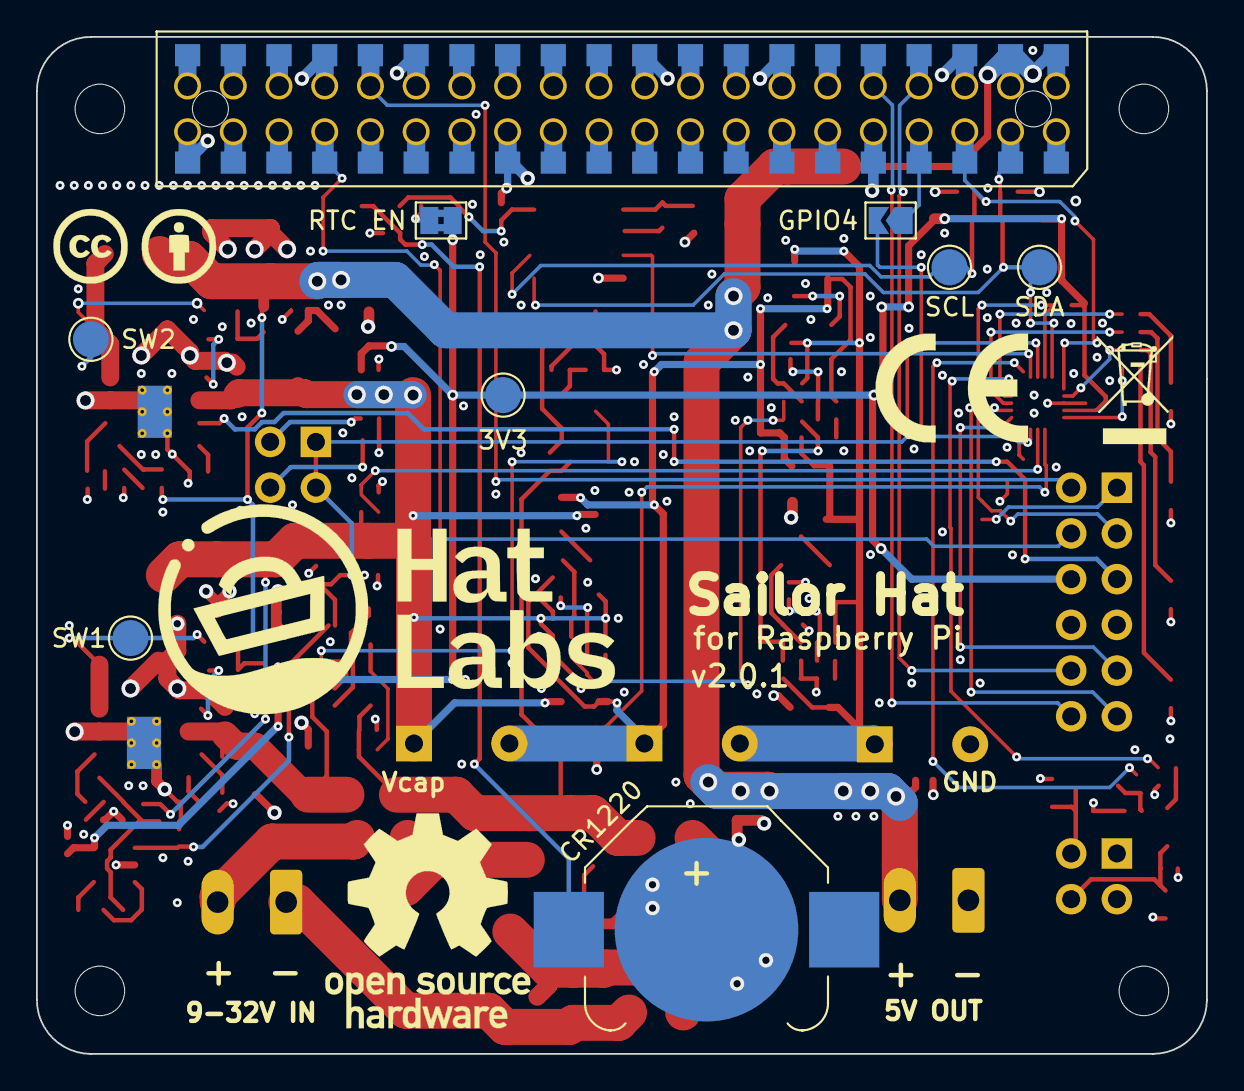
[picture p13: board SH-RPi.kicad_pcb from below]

Board: 4 copper layers, 65.0 x 56.5 mm, 168 parts (14 on the bottom side), 92 nets.

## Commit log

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2020-01-08 Added hardware schematics to the project
    [RPi_GPIO.sch, RTC.sch, canbus.sch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]
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2020-01-08 added a pull-up resistor to ATtiny reset pin
    [inv_Sense_Vcc.sch]
2020-01-08 Add an output cap to the MT3608.
    [voltage_output.sch]
2020-01-08 Implement next hardware revision
    [RTC.sch, boost.sch, buck.sch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]
2020-01-08 fix a silk screen error by swapping R14 and R15
    [buck.sch, pi-supercap-ups.kicad_pcb]
2020-01-08 Changed to pure-serial topology. Changed to beefier mcu.
    [LDO3V3.sch, RTC.sch, boost.sch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]
2020-01-08 Layout partially done before change of plans
    [boost.sch, buck.sch, canbus.sch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]
2020-01-08 revE ready for production
    [RTC.sch, boost.sch, buck.sch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]
2020-01-08 Fixed wrong footprints & passive component values.
    [boost.sch, buck.sch, pi-supercap-ups.kicad_pcb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]
2020-01-08 Redesign SMPS layouts.
    [boost.sch, pi-supercap-ups.kicad_pcb]
2020-01-08 C7 is not required and can be made virtual
    [pi-supercap-ups.kicad_pcb]
2020-01-08 Add ENIN trace to the PCB. Change input voltage dividers for 1.1V ref.
    [buck.sch, current_limiting.sch, inv_Sense_Vcc.sch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]
2020-01-08 Fix component values etc
    [buck.sch, current_limiting.sch, inv_Sense_Vcc.sch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]
2020-01-10 Move contents from hardware/ to repo root
    [LDO3V3.sch, RPi_GPIO.sch, boost.sch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]
2020-01-10 Rename to Sailor Hat
    [LDO3V3.sch, boost.sch, buck.sch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]
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2020-01-14 Update MCU to ATtiny841
    [inv_Sense_Vcc.sch]
2020-01-17 Implement better current limiting
    [boost.sch, buck.sch, canbus.sch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]
2020-01-17 Add test points for new features
    [buck.sch, sailor-hat.sch]
2020-01-17 Annotate and tweak power flags
    [boost.sch, buck.sch, inv_Sense_Vcc.sch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]
2020-01-20 Add graphics to PCB silk screen
    [sailor-hat.kicad_pcb]
2020-01-20 Update licence, tweaks to footprints and ERC
    [boost.sch, buck.sch, canbus.sch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]
2020-01-22 Update the README, add a new rendered image of the board
    [inv_Sense_Vcc.sch, protection.sch, sailor-hat.sch]
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2020-02-27 Need a cap to cool down current limiting FB loop
    [buck.sch]
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2020-02-29 Fix diode footprint
    [buck.sch, inv_Sense_Vcc.sch]
2020-02-29 Prevent reverse current through regulator
    [buck.sch]
2020-02-29 Make protection TVS bidirectional
    [protection.sch]
2020-02-29 Swap CAN0 and CAN1 connectors; use GPIO 5 & 6 for CAN interrupts for Moitessier compatibility
    [sailor-hat.sch]
2020-02-29 Implement revH changes in PCB
    [sailor-hat.kicad_pcb]
2020-03-01 Add a voltage divider for indicating HW version
    [canbus.sch, inv_Sense_Vcc.sch, sailor-hat.kicad_pcb]
2020-03-09 Add LCSC part numbers to components
    [boost.sch, buck.sch, canbus.sch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]
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2020-08-19 Optimize PCB layout; add missing filter caps
    [canbus.sch, sailor-hat.kicad_pcb, sailor-hat.sch]
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2020-09-03 Revert back to using INA199 as a current limiter
    [boost.sch, buck.sch, canbus.sch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]
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2020-09-03 Swap CAN power rectifier diode into a smaller one
    [protection.sch, sailor-hat.kicad_pcb]
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2020-11-16 Redesigned layout to take EMC issues better into account
    [IO.sch, boost.sch, buck.sch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]
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2020-11-17 Fix DRC errors
    [sailor-hat.kicad_pcb]
2020-11-19 Change CAN termination jumper to a solder jumper
    [canbus.sch, sailor-hat.kicad_pcb]
2020-11-19 Flipped the battery to the top side of the board
    [sailor-hat.kicad_pcb]
2020-11-26 Make power connector identical to SH-ESP32 for consistency
    [IO.sch, protection.sch, rtc.sch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]
2020-11-26 Nudge GPIO connector silk screen legend a bit down
    [sailor-hat.kicad_pcb]
2020-11-26 Add missing LCSC part numbers
    [IO.sch, canbus.sch, control_mcu.sch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]
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2020-11-27 Make power traces around DC-DC converters as wide as possible
    Some traces also converted to fill areas
    [sailor-hat.kicad_pcb]
2020-11-27 Rename project files to follow the conventions in SH-ESP32
    [IO.sch, SH-RPi.kicad_pcb, SH-RPi.sch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]
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2020-11-27 Updated the title block and one THT terminal part number
    [IO.sch, SH-RPi.kicad_pcb]
2020-11-27 Update the BAT54C part number according to availability
    [control_mcu.sch]
2020-12-10 Extend the PCB size to provide space for an onboard supercapacitor
    The PCB was extended to the left by 21mm to provide room for a
    18x40mm (max 18x42mm) 50/60F supercapacitor. The supercapacitor
    is lodged in a slot on the PCB to provide mechanical stability and limit
    the maximum height of the assembly. It now requires 14mm of headroom.
    Additionally, the following changes were made:
    - the external supercap connector was removed
    - the power and CAN connectors were swapped to JST XH
    - there is space for a wire link between CAN and power conx
    - power protection circuitry was moved to the edge of the board
    - 3.3V regulator was moved to improve the layout
    - a 100pF cap was added to the boost feed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
    [IO.sch, SH-RPi.kicad_pcb, SH-RPi.sch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]
2020-12-16 Route I2C to unique pins
    Also:
    - Connect RTC interrupt to ATtiny
    - Break out the interrupt pin to a connector for external signaling
    [IO.sch, SH-RPi.kicad_pcb, SH-RPi.sch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]
2020-12-17 Split the 120R CAN termination resistor into two 240R
    Increase the thermal clearances on copper fills
    [SH-RPi.kicad_pcb, canbus.sch, control_mcu.sch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]
2020-12-19 Change the MCU to ATTiny1614
    - Rewired the PCB due to changed pins
    - Cleaned up network names around the MCU
    - Use a basic part Schottky for the buck converter
    - Change MCP2515 crystal to 16MHz basic part
    - Change BAT54C to two discrete schottkys
    - Change the SOD-523 schottky to MSK4005
    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
    [IO.sch, SH-RPi.kicad_pcb, SH-RPi.sch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]
2020-12-19 Fixed the VCap trace and fill
    [SH-RPi.kicad_pcb]
2020-12-19 Improved LED traces to allow more continuous ground frame around the supercap slot
    [SH-RPi.kicad_pcb]
2021-01-29 Remove CAN bus RCLAMP (N2K spec requires that +-18V can be connected to any input)
    [canbus.sch]
2021-01-29 Replace polyfuse with a regular fuse
    [protection.sch]
2021-02-01 Modify boost stage design according to WEBENCH results
    [boost.sch]
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2021-02-04 Buck stage redesigned with a new IC and current limiter
    [buck.sch]
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2021-02-08 Remove undersized ferrite bead, shuffle power protection circuitry
    Also add new logo & generic cleanup
    [SH-RPi.kicad_pcb, buck.sch, pcb.sch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]
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2021-02-08 Change boost FB resistors to JLC basic ones
    [SH-RPi.kicad_pcb, boost.sch]
2021-02-15 Add LCSC part number for the boost converter
    [boost.sch]
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2021-02-19 Add a note for the new mystery hole
    [pcb.sch]
2021-02-19 Add an LCSC part no. for the battery clip
    [rtc.sch]
2021-03-24 Replace current limiting op amp with a RRIO one
    [SH-RPi.kicad_pcb, buck.sch]
2021-03-26 Update the current limiter design and swap the signal diodes
    [SH-RPi.kicad_pcb, buck.sch, control_mcu.sch]
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2021-03-27 Revert I2C pins back to defaults
    - What was I thinking?
    - Also improve silk screen labeling around headers and connectors
    [IO.sch, SH-RPi.kicad_pcb]
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2021-08-19 Tweak a text box comment to make it more accurate
    [control_mcu.sch]
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2021-11-18 Fix broken symbols
    [IO.kicad_sch, boost.kicad_sch, buck.kicad_sch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]
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2021-11-18 Revert the Rev. 1.0.1 LDO change
    The new part exhibited severe startup overshoot
    which disabled or even damaged the MCU.
    [SH-RPi.kicad_pcb, SH-RPi.kicad_sch, buck.kicad_sch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]
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2022-10-16 Use a battery clip instead of a cell
    [SH-RPi.kicad_sch, rtc.kicad_sch]
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2022-10-19 Add more reference vias and barrier around the oscillator
    [SH-RPi.kicad_pcb]
2022-10-21 Replace "ideal diode" with Schottky & other changes
    [IO.kicad_sch, SH-RPi.kicad_pcb, SH-RPi.kicad_sch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]
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2022-10-24 Redesign the EMI input filter
    [SH-RPi.kicad_pcb, SH-RPi.kicad_sch, buck_stage_1.kicad_sch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]
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2022-10-25 Exclude supercaps and graphics from BOM and POS files
    [SH-RPi.kicad_pcb]
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2022-10-25 Update title block date for schematic and pcb
    [IO.kicad_sch, SH-RPi.kicad_pcb, SH-RPi.kicad_sch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]
2022-11-26 Fix LDO reference font size
    [ldo.kicad_sch]
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2022-12-06 Update LED GPIO pins to allow PWM output
    [control_mcu.kicad_sch]
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2022-12-19 Insert additional input caps to reduce conducted noise
    [SH-RPi.kicad_sch]
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2022-12-28 Flip the pass through connector to bottom side
    [IO.kicad_sch, SH-RPi.kicad_pcb, SH-RPi.kicad_sch]
2022-12-28 Add missing footprints and 3d models
    [CP_Radial_L25_D12.5_P5.3_Horizontal.step]
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2022-12-28 Increase copper edge clearance to 0.4 mm
    [SH-RPi.kicad_pcb]
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2022-12-28 Update passthrough socket footprint to fit in copper area
    [SH-RPi.kicad_pcb]
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2022-12-28 Change stage 1 switching diode due to part availability
    [SH-RPi.kicad_pcb, SH-RPi.kicad_sch, buck_stage_1.kicad_sch]
2022-12-28 Fix J301 part number
    [SH-RPi.kicad_pcb, SH-RPi.kicad_sch, buck_stage_1.kicad_sch]
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2023-01-28 Replace the GPIO connector with FH-00339
    [IO.kicad_sch, SH-RPi.kicad_pcb, SH-RPi.kicad_sch]
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2023-01-28 Correct part LCSC codes and values
    [SH-RPi.kicad_pcb, SH-RPi.kicad_sch, control_mcu.kicad_sch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]
2023-01-30 Remove solder paste from the battery holder center mask
    [SH-RPi.kicad_pcb]
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2023-08-02 Update C312 and R306
    These changes fix the too high startup voltage and the first stage
    buck converter stability issues.
    [IO.kicad_sch, SH-RPi.kicad_sch, buck_stage_1.kicad_sch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]
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2024-09-25 Fix the passthrough socket footprint
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2024-09-25 Replace parts due to lack of availability
    [SH-RPi.kicad_pcb, buck_stage_1.kicad_sch, control_mcu.kicad_sch]
2024-11-17 Rename power input sheets
    Also tweak pass-through connector solder paste margins.
    [SH-RPi.kicad_pcb, SH-RPi.kicad_sch, buck_5V.kicad_sch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]
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

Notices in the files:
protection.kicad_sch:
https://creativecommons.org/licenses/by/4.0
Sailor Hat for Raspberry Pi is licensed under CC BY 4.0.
